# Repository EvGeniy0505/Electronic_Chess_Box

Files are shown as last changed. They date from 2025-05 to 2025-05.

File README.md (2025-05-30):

# 🧠 Electronic Chess Box

**Electronic Chess Box** — это проект умной электронной шахматной доски, разработанный на базе Arduino. 

Он сочетает в себе аппаратную и программную части, позволяя играть в шахматы с использованием физических фигур, при этом отслеживая ходы и взаимодействуя с шахматным движком.

## 📁 Структура проекта

Репозиторий организован следующим образом:

```
Electronic_Chess_Box/
├── .vscode/                 # Настройки среды разработки Visual Studio Code
├── code/                    # Исходный код прошивки и скриптов
│   ├── arduino/             # Код для микроконтроллера Arduino
│   ├── chess_engine/        # Код для нашего шахматного движка
│   └── communication/       # Код для связи Arduino и движка
├── models/                  # 3D-модели и схемы конструкции
├── Умные шахматы.pdf        # Документация проекта
├── Умные шахматы.pptx       # Презентация проекта
├── chess_poster.png         # Постер проекта
└── .gitignore               # Файл исключений Git
```

## ⚙️ Аппаратные компоненты

Arduino Uno — управление сенсорами и считывание ходов.

Герконы — определение положения фигур на доске.

Светодиоды (LED) — индикация возможных ходов и подсказок.

3D-печатные компоненты — корпус и элементы доски.

## 🚀 Начало работы

Сборка аппаратной части: следуйте инструкциям в документации и используйте модели из папки models/ для печати необходимых компонентов.

Прошивка Arduino: загрузите код из папки code/arduino/ с помощью Arduino IDE.

Запуск игры:
```bash
cd code/communication
python3 main.py
``` 
После включения системы, доска готова к игре. Фигуры автоматически распознаются, и возможные ходы подсвечиваются.

## 📄 Документация

**Умные шахматы.pdf** — подробное описание проекта, включая схемы и инструкции.

**Умные шахматы.pptx** — презентация проекта для демонстрации.

**chess_poster.png** — визуальный постер проекта.

## 📬 Обратная связь

Если у вас есть предложения или вы обнаружили ошибки, пожалуйста, создайте **issue** или отправьте **pull request**.

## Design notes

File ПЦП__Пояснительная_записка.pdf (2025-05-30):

## Электронная шахматная доска на герконовых датчиках

Команда

Хальфин Бахтияр | khalfin.br@phystech.edu
Б01-302 | Занимался электроникой и настраивал логику для
| связи всех компонентов. Сделал все модели шахмат-
| ных фигур. Участвовал в написании приложения для
| шахмат.
Евгений Рогов | rogov.ev@phystech.edu
Б01-304 | Проектировал корпус для доски. Занимался печатью
| и лазерной резкой всех компонентов. Участвовал в
| написании приложения для шахмат.
Новикова Полина | novikova.pp@phystech.edu
Б01-304 | Припаяла все элементы к печатной плате, собрала
| матрицу герконов и LED-ленту. Сделала все доку-
| менты для проекта: постер, презентацию и поясни-
| тельную записку.

Причины выбора проекта

С недавнего времени наша команда увлеклась игрой в шахматы. Поэтому мы решили выполнить работу, которая будет сочетать наше хобби и полезный проект, с помощью которого можно будет играть в шахматы не только вдвоём, но и с компьютером. Причём с возможностью физического взаимодействия с фигурами.

Цель проекта

Разработать и изготовить электронную шахматную доску, позволяющую пользователю играть с компьютером. Доска будет оснащена герконовыми датчиками в каждой клетке и магнитами в каждой фигуре для определения ходов, а также LEDподсветкой для индикации возможных ходов и ходов соперника.

Задачи проекта

- Разработать конструкцию шахматной доски с герконами в каждой клетке и магнитами в каждой фигуре;
- Создать программу для определения ходов и взаимодействия с компьютером;
- Разработать систему LED-подсветки для отображения возможных ходов и ходов компьютера/другого игрока;
- Собрать прототип доски и провести тестирование функциональности;
- Настроить программное обеспечение для корректного взаимодействия с доской;
- Провести финальное тестирование и отладку системы.

Описание продукта

Мы разработали умную шахматную доску, способную отслеживать ходы игрока с помощью герконовых датчиков и подсвечивать клетки для следующего действия. Основные функции:

- Распознавание перемещений фигур в реальном времени;
- Подсветка ходов с помощью встроенной светодиодной матрицы;
- Игра с локальным шахматным движком собственного производства;
- Подключение к Lichess.org через API — можно играть с живыми соперниками;
- Поддержка обратной связи: доска сама показывает следующий ход, ожидая действий игрока.

Аппаратная часть построена на Arduino Nano. Программная логика реализована на C++. Возможна интеграция с companion-приложением или удалённым интерфейсом управления.

Решение задач и описание процесса изготовления

1. Корпус для шахматной доски был спроектирован в SolidWorks и изготовлен с помощью лазерной резки;
2. Фигуры были смоделированы в Blender и напечатаны на 3D-принтере;
3. Печатная плата для электроники спроектирована в EasyEDA, затем изготовлена на фрезерном станке;
4. Для герконов была использована макетная плата из-за отсутствия подходящей по размеру печатной платы;
5. Затем был написан код для Arduino и выложен на GitHub (https://github.com/EvGeniy0505/Electronic_Chess_Box) проекта.

Компоненты

Для электроники использовались следующие компоненты:

- Arduino Nano;
- Герконы;
- LED-лента;
- Магниты;
- Bluetooth-модуль;
- BMS-модуль;
- Сдвиговые регистры;
- Модуль понижения напряжения;
- Держатель для аккумуляторов;
- Зарядный модуль.

Существующие аналоги

Конструкция аналогичной шахматной доски описывается, например, в:

1. GoChess (https://particula-tech.com/pages/gochess?_ab=0&_fd=0&_sc=1) — шахматная доска, позволяющая играть по сети с автоматическим перемещением фигур соперника. Поддерживает голосовое управление и подсветку возможных ходов. Недостаток этого аналога — высокая стоимость разработки. В нашем проекте использованы недорогие компоненты при сохранении качественного функционала;
2. DIY Super Smart Chessboard | Play Online or Against Raspberry Pi - Instructables, (https://www.instructables.com/DIY-Super-Smart-Chessboard-Play-Online-or-Against-/)
где создание аналогичной установки описано в 34 шагах. Недостаток — необходимость ручного подтверждения сделанных ходов. В нашем продукте это не требуется.

Можно отметить, что в России отсутствует массовое производство умных шахматных досок.

Тестирование

Приложение для шахмат было протестировано, связь с lichess.org работает. После чего была протестирована доска.
Проведено несколько этапов тестирования:
- Проверка корректной регистрации ходов при различных сценариях перемещения фигур;
- Проверка индикации возможных ходов и подсветки с помощью светодиодной матрицы;
- Тестирование устойчивости Bluetooth-соединения и передачи данных между доской и companion-приложением;
- Интеграционные тесты на связку "доска — шахматный движок — пользователь";
- Тестирование работы доски при игре с живыми соперниками через Lichess API.

Результаты тестов показали высокую надёжность системы: ошибки определения ходов возникали редко и в основном были связаны с недостаточной точностью размещения магнитов. После калибровки доска демонстрировала стабильную и корректную работу.

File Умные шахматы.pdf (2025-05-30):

# Умные шахматы

Новикова Полина
Рогов Евгений
Бахтияр Хальфин

# Цели проекта

- Сделать шахматы с умной подсветкой
- Закрепить навыки полученные в прошлом семестре
- Написать и подключить собственный движок с возможностью игры на lichess.org

# Принцип работы

В каждой фигуре находится магнитик. При поднятии фигуры программа понимает какую из фигур поднял игрок.

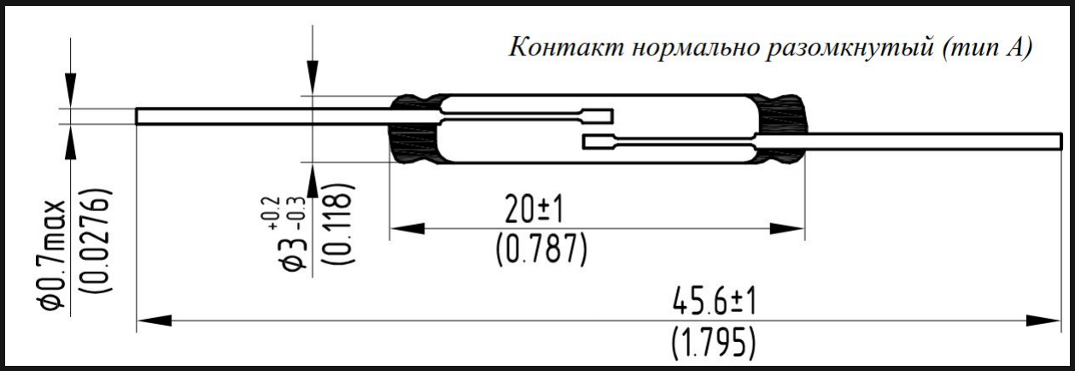
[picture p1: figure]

# Последовательность действий

- Развести и напечатать плату
- Припаять к ней все необходимые детали
- Сделать корпус на лазерном станке, используя технику шип паз
- Распечатать шахматные фигуры на 3d принтере
- Написать собственный движок для игры с компьютером
- Подключить к сайту lichess.org для игры с компьютером на шахматной доске

# Электроника

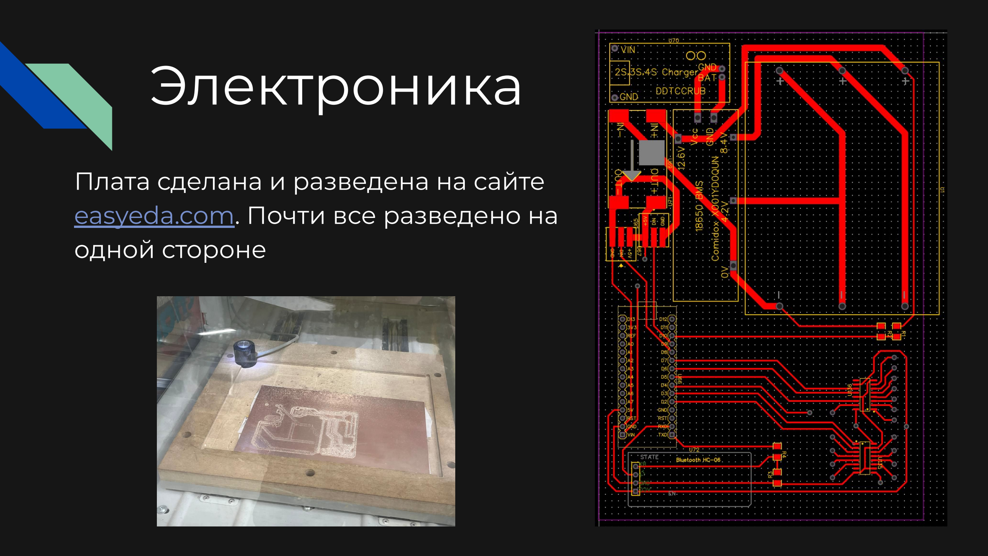
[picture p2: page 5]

Плата сделана и разведена на сайте easyeda.com. Почти все разведено на одной стороне

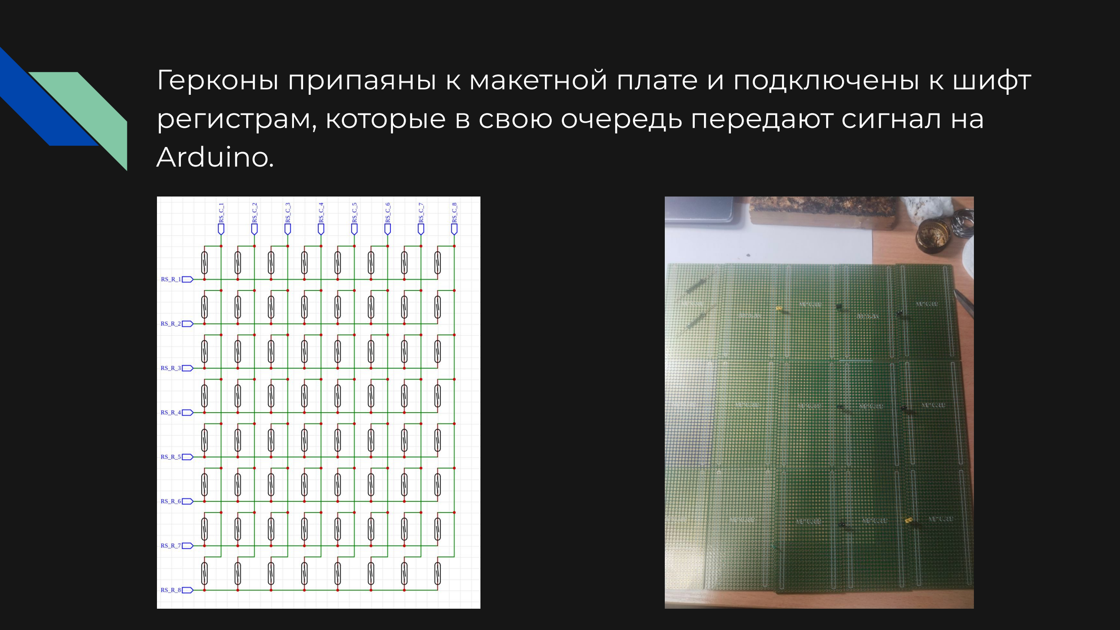
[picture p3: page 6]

Герконы припаяны к макетной плате и подключены к шифт регистрам, которые в свою очередь передают сигнал на Arduino.

# Результат

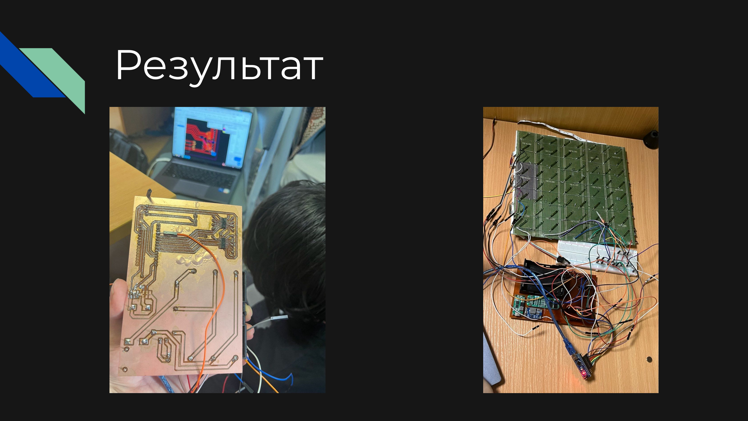
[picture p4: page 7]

# Корпус

Корпус был сделан в программе SolidWorks. После чего мы проверили его сборку и распечатали на лазерном станке

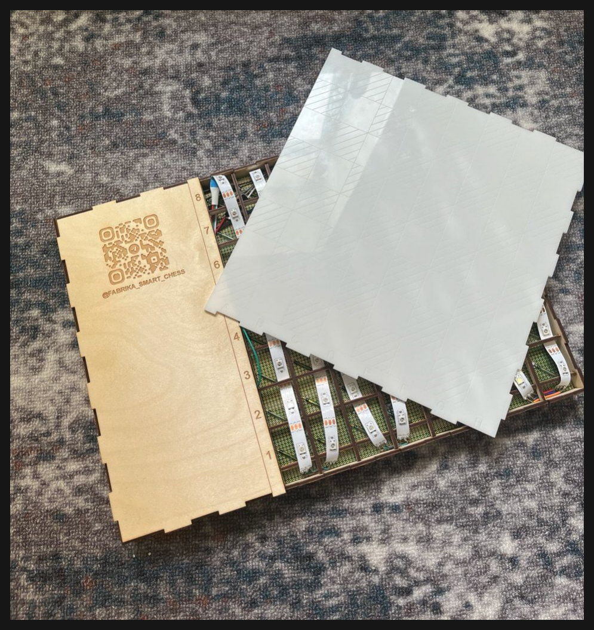
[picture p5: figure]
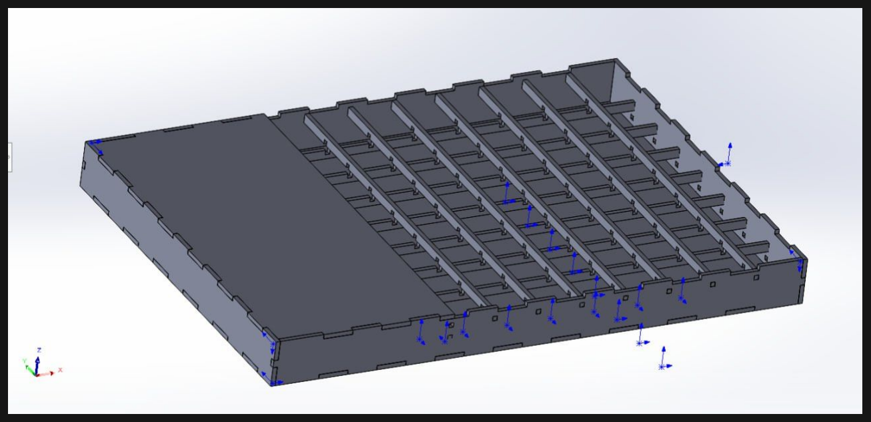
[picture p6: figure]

# Шахматные фигуры

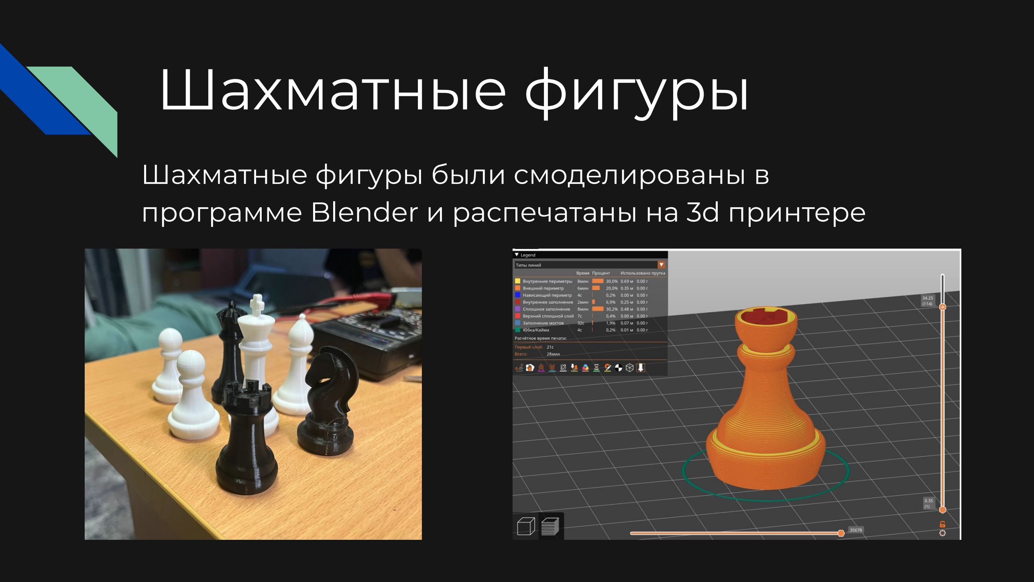
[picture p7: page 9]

Шахматные фигуры были смоделированы в программе Blender и распечатаны на 3d принтере

# Шахматный движок

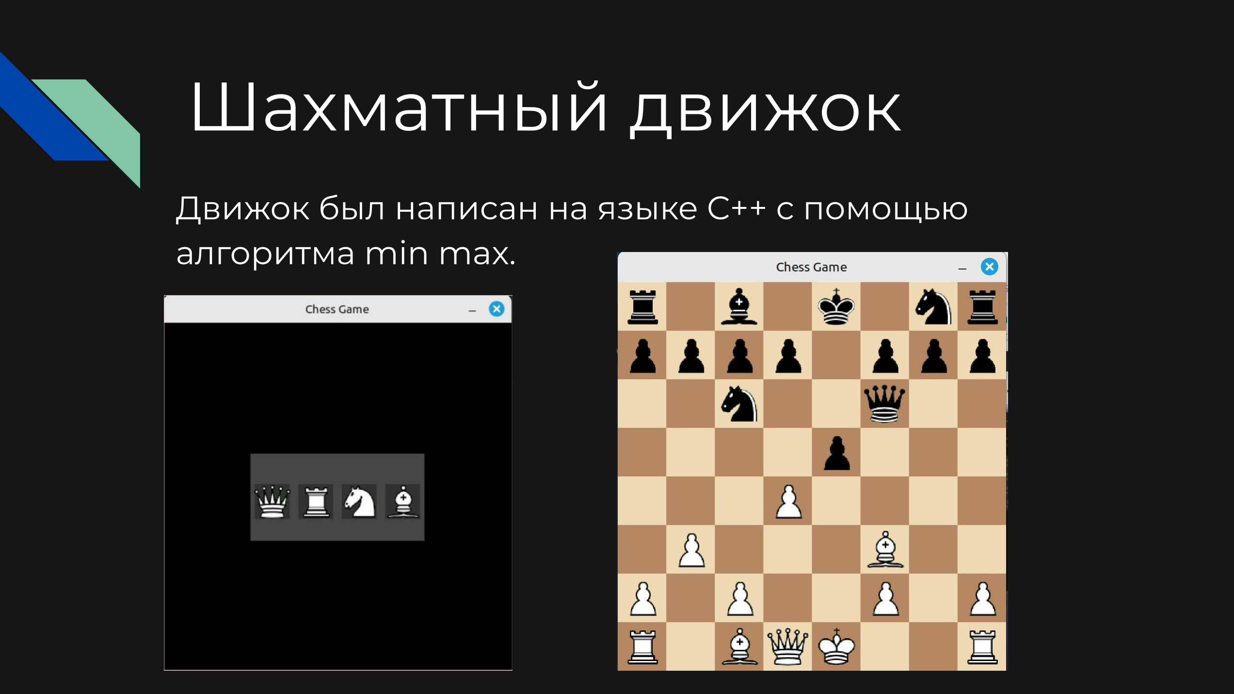
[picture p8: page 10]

Движок был написан на языке C++ с помощью алгоритма min max.

После чего в него добавлена база шахматных дебютов, написана визуализация на основе графической библиотеки sdl2 и подключен к сайту lichess.org

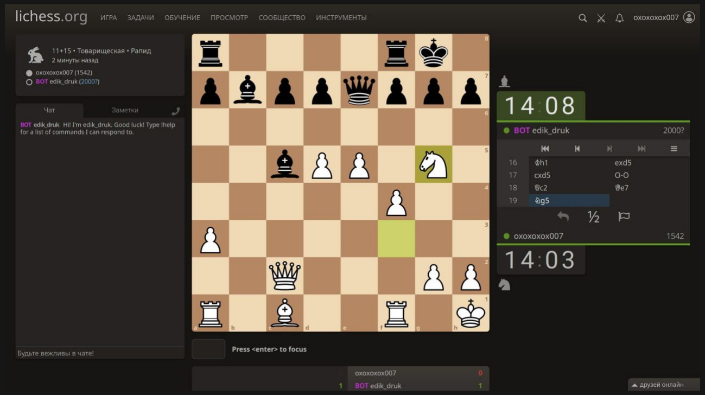
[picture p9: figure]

# Результаты

Доска протестирована нашей командой и работает

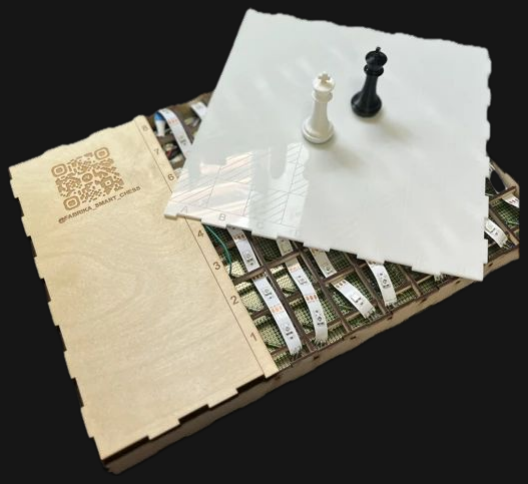
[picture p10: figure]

# Усовершенствование проекта

- Поставить вместо герконовых датчиков NFC метки
- Сделать клетки доски больше или магниты в фигурах
- Сделать каждую ячейку обособленно
- Наладить широкое производство

# Полезные ссылки

Телеграм канал: https://t.me/fabrika_smart_chess Github проекта:
https://github.com/EvGeniy0505/Electronic_Chess_Box Github шахматного движка:
https://github.com/EvGeniy0505/Chess_Engine

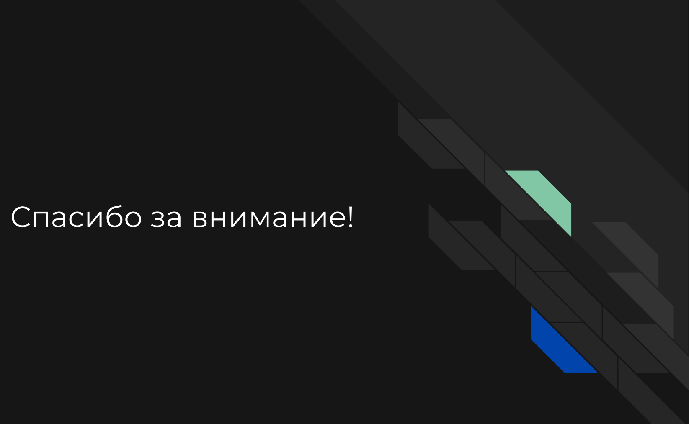
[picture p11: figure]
Спасибо за внимание!

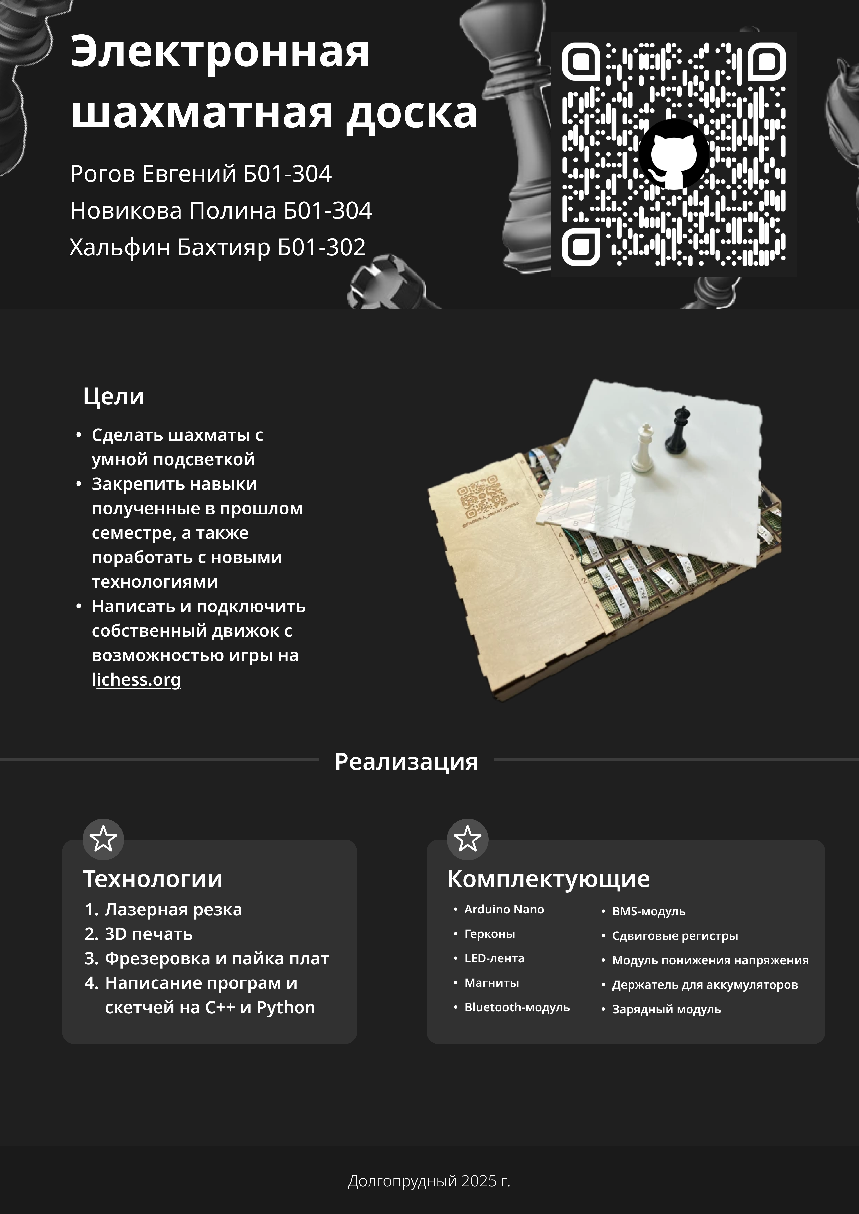
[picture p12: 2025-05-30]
chess_poster.png

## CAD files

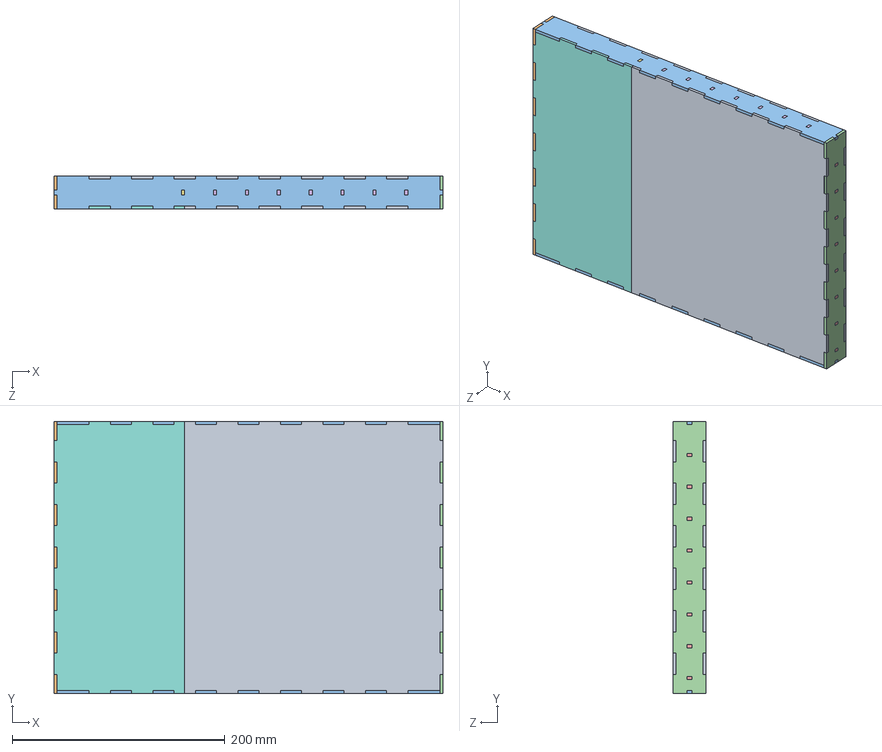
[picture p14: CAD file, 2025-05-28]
models/board/assembly.SLDASM
366.0 x 256.0 x 31.0 mm
bottom
left
front x 2
right
перегородка x 8
перегородка2 x 7
перегородка3
top1
top2

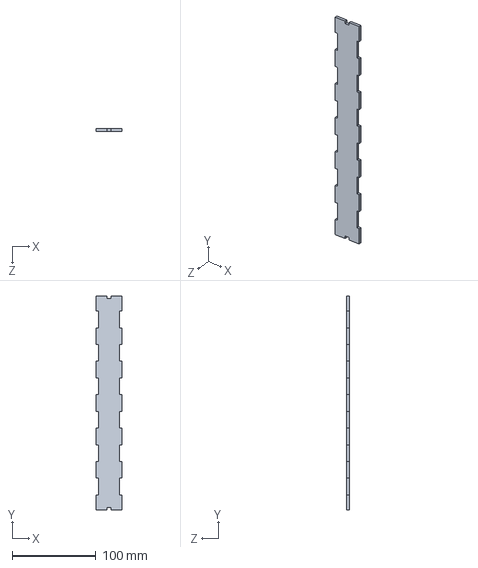
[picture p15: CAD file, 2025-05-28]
models/board/left.SLDPRT
31.0 x 256.0 x 3.00 mm

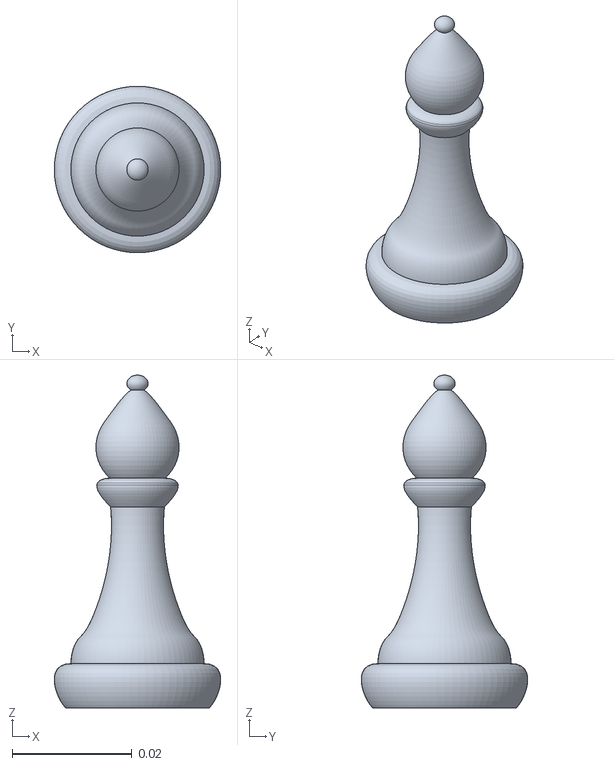
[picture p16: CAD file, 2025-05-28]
models/pieces/bishop.stl
0.0278 x 0.0278 x 0.0557

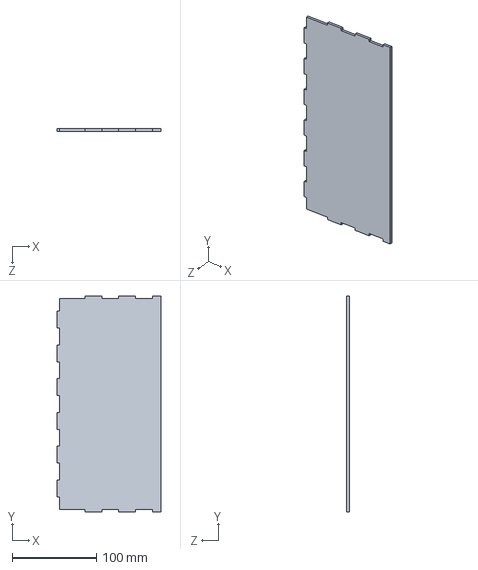
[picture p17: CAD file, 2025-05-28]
models/board/top_left.SLDPRT
123.0 x 256.0 x 3.00 mm

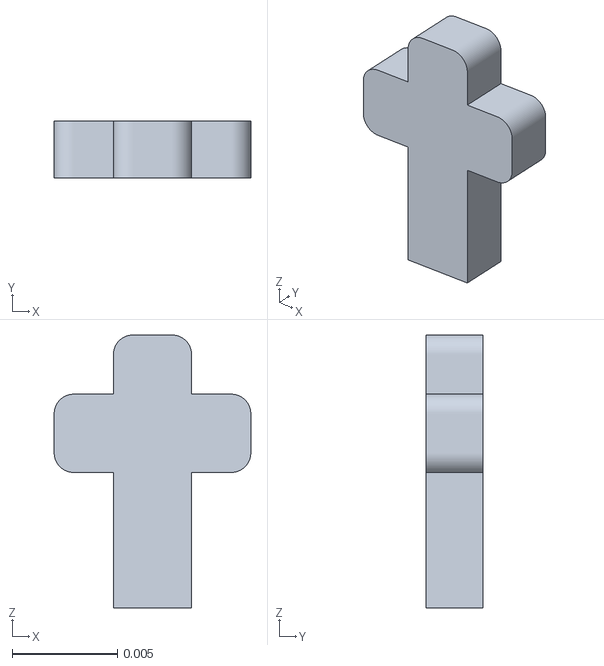
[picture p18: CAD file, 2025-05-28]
models/pieces/king-cross.stl
0.00932 x 0.00269 x 0.0129

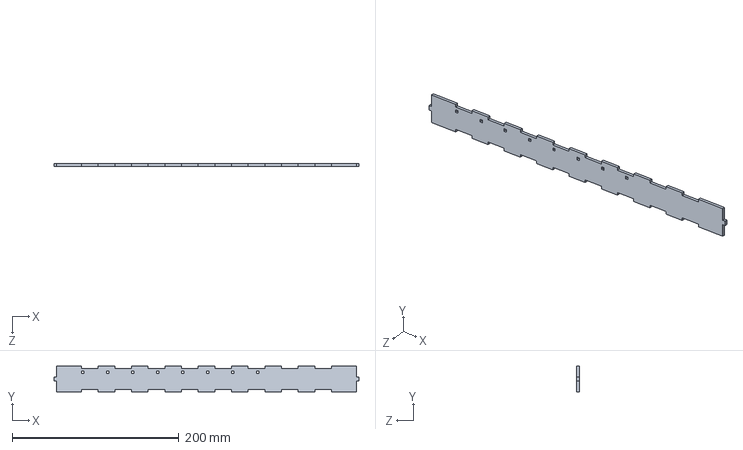
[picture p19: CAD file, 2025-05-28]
models/board/front.SLDPRT
366.0 x 31.0 x 3.00 mm

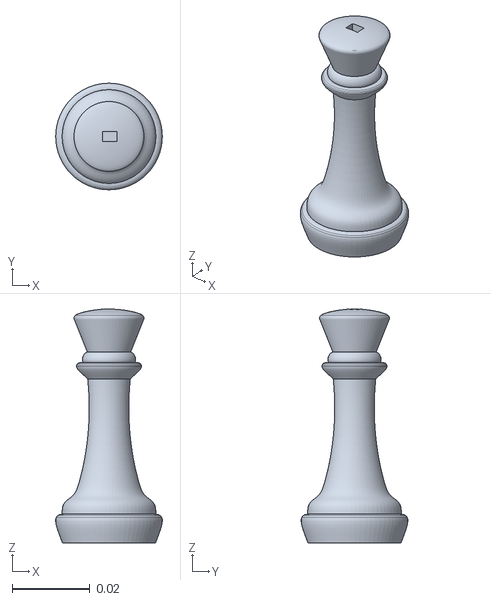
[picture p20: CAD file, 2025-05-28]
models/pieces/king-body.stl
0.0274 x 0.0274 x 0.0602

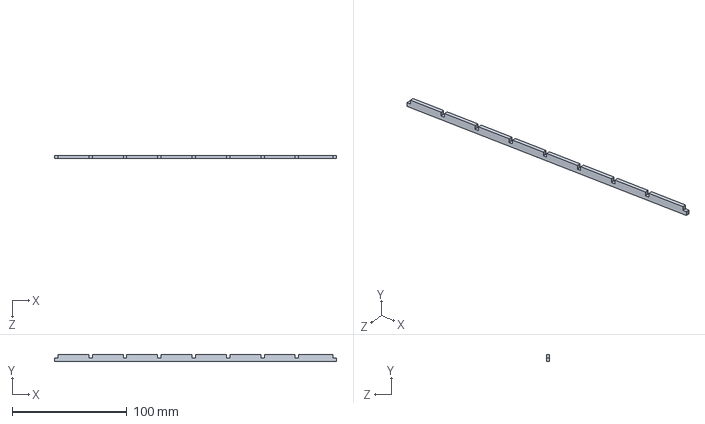
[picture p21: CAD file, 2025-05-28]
models/board/separator.SLDPRT
246.0 x 6.00 x 3.00 mm

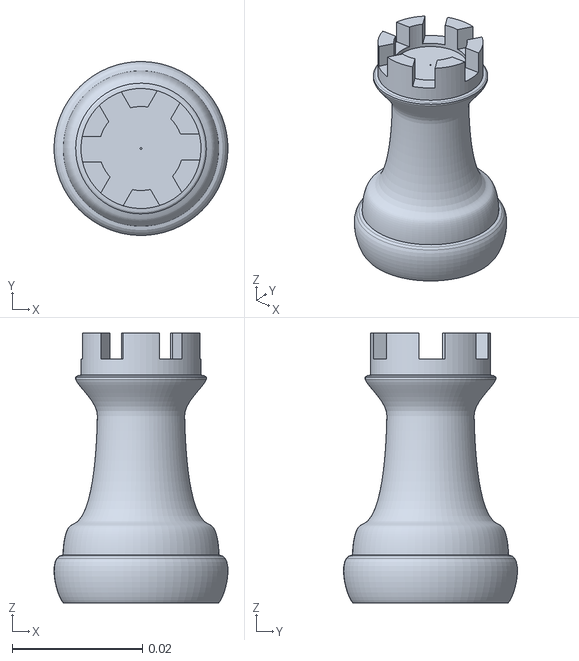
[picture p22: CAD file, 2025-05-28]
models/pieces/rook.stl
0.0268 x 0.0268 x 0.0415

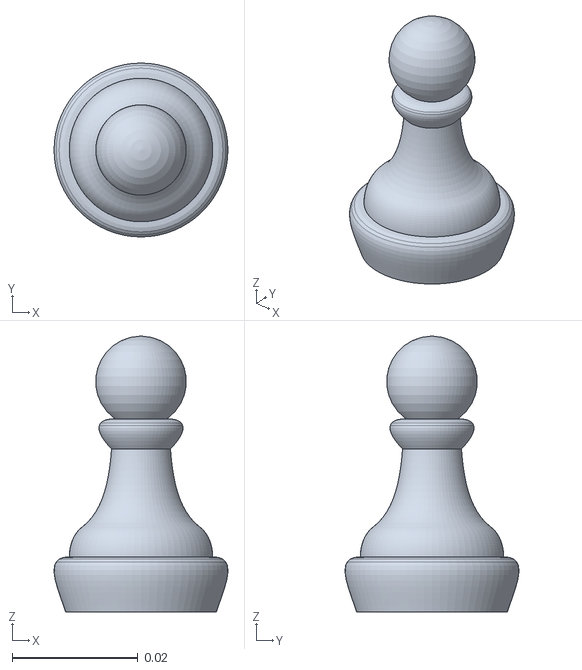
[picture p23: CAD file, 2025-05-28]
models/pieces/pawn.stl
0.0277 x 0.0277 x 0.0439

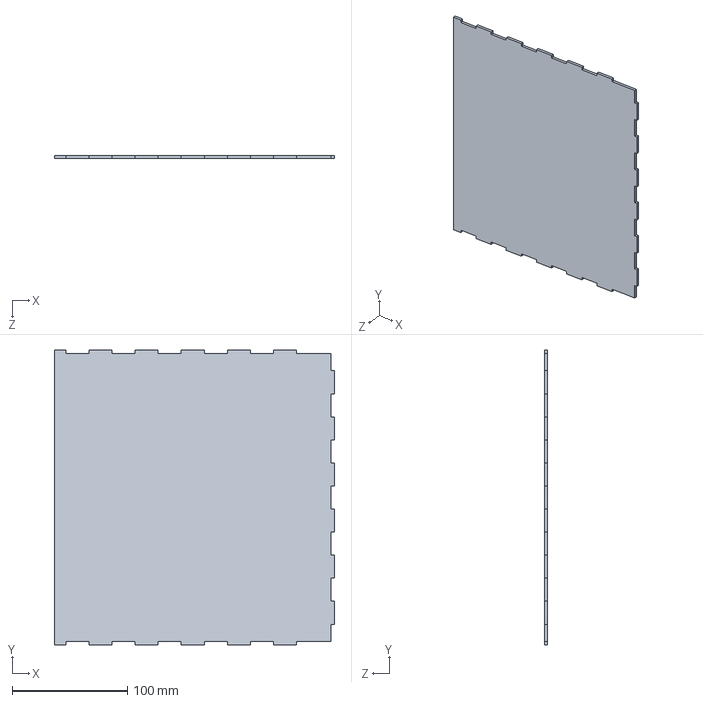
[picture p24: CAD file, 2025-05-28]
models/board/top_right.SLDPRT
243.0 x 256.0 x 3.00 mm

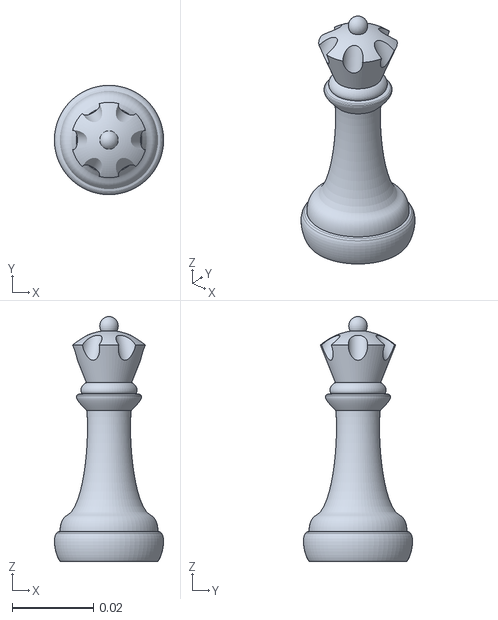
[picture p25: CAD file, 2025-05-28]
models/pieces/queen.stl
0.0269 x 0.0269 x 0.0603

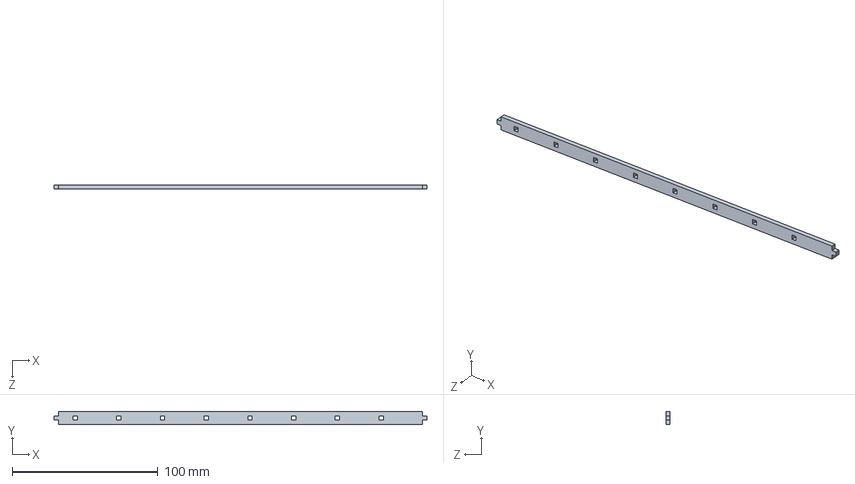
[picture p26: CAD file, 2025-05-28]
models/board/separator3.SLDPRT
256.0 x 9.00 x 3.00 mm

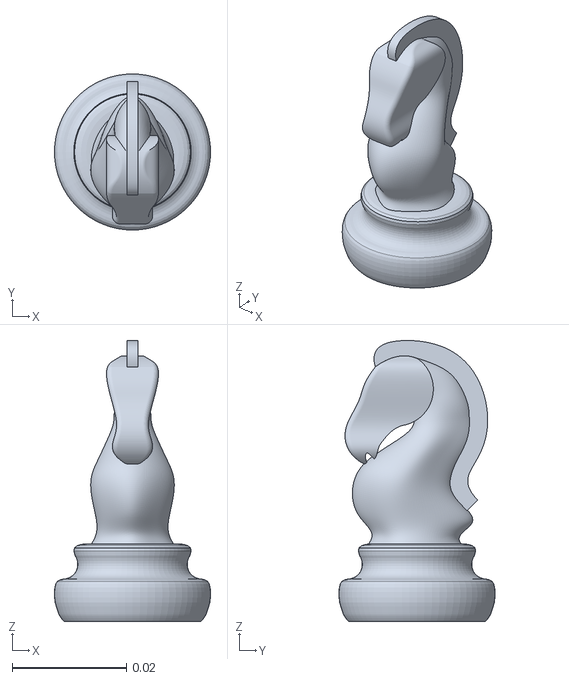
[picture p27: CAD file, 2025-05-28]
models/pieces/knight.stl
0.0274 x 0.0274 x 0.0493

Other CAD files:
models/board/right.SLDPRT
models/board/bottom.SLDPRT
models/board/separator2.SLDPRT

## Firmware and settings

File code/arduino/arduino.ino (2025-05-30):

#include "config.h"
#include "shift_registers.h"
#include "reed_matrix.h"
#include "bluetooth.h"
#include "led_control.h"  // Добавляем заголовочный файл для управления светодиодами

ShiftRegisters shiftRegisters;
ReedMatrix reedMatrix(shiftRegisters);
Bluetooth bluetooth;
LedControl ledControl(reedMatrix);  // Создаем экземпляр управления светодиодами

// Для отслеживания изменений
byte lastBoardState[BOARD_SIZE] = {0};

void setup() {
    Serial.begin(115200);
    
    shiftRegisters.init();
    reedMatrix.init();
    bluetooth.init();
    ledControl.init();  // Инициализируем светодиоды
    
    Serial.println("Chess Board Initialized");
    Serial.println("Waiting for Bluetooth connection...");
    
    // Первоначальное обновление светодиодов
    ledControl.updateFromReedMatrix();
}

void loop() {
    // 1. Сканируем состояние герконов
    reedMatrix.scan();
    
    // 2. Проверяем изменения
    //if (hasBoardChanged()) {
        // 3. Отправляем только при изменениях
        bluetooth.sendBoardState(reedMatrix.getBoardState());
       
        printMatrixState(reedMatrix.getBoardState());
        
        // Обновляем светодиоды при изменении состояния
        ledControl.updateFromReedMatrix();
    //}
    
    // 4. Проверяем обратную связь
    checkBluetoothFeedback();
    
    delay(50); // Уменьшенная задержка
}

// Остальные функции остаются без изменений

bool hasBoardChanged() {
    byte* current = reedMatrix.getBoardState();
    for (byte i = 0; i < BOARD_SIZE; i++) {
        if (current[i] != lastBoardState[i]) {
            memcpy(lastBoardState, current, BOARD_SIZE);
            return true;
        }
    }
    return false;
}

void printMatrixState(byte* boardState) {
    Serial.println("Matrix state (Debug):");
    for (byte row = 0; row < BOARD_SIZE; row++) {
        for (byte col = 0; col < BOARD_SIZE; col++) {
            Serial.print((boardState[col] & (1 << row)) ? "1 " : "0 ");
        }
        Serial.println();
    }
    Serial.println();
}

void checkBluetoothFeedback() {
    while (bluetooth.btSerial.available()) {
        String feedback = bluetooth.btSerial.readStringUntil('\n');
        feedback.trim();
        
        Serial.print("[BT Feedback] ");  // Метка для отладки
        Serial.println(feedback);  // Вывод всего сообщения
        
        if (feedback.startsWith("ERROR:")) {
            String errorMsg = feedback.substring(6);
            Serial.print("Ошибка хода: ");
            Serial.println(errorMsg);
        }
        else if (feedback.startsWith("MOVE:")) {
            String move = feedback.substring(5);
            Serial.print("Принят ход: ");
            Serial.println(move);
        }
    }
}

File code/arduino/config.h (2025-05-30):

#ifndef CONFIG_H
#define CONFIG_H

// Пины 74HC595 (выходные - столбцы)
#define LATCH_PIN_OUT 6     // CS_595 (Latch)
#define DATA_PIN_OUT 5       // DAT_595
#define CLOCK_PIN_OUT 7      // CLK_595

// Пины 74HC165 (входные - строки)
#define LATCH_PIN_IN 3       // LAT_165 (Load)
#define DATA_PIN_IN 4        // DAT_165
#define CLOCK_PIN_IN 2       // CLK_165

// Bluetooth пины
#define BT_TX_PIN 8          // Пин TX Bluetooth
#define BT_RX_PIN 9         // Пин RX Bluetooth

// Константы
#define BOARD_SIZE 8         // Размер шахматной доски (8x8)

// LED Configuration
#define LED_PIN 11           // Пин, к которому подключена лента
#define LED_COUNT 64        // 8x8 = 64 светодиода
#define LED_ON_COLOR strip.Color(0, 255, 0)  // Зеленый цвет для занятых клеток
#define LED_OFF_COLOR strip.Color(0, 0, 0)   // Выключенный светодиод

#endif

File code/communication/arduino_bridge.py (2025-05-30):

import os
import subprocess
import time
import serial
from collections import defaultdict, deque

BOARD_SIZE = 8
SAMPLE_SIZE = 5
STABLE_THRESHOLD = 3
FIFO_IN_PATH = "./build/arduino_in"
FIFO_OUT_PATH = "./build/arduino_out"

class ChessBoardAnalyzer:
    def __init__(self, serial_conn, fifo_path="/tmp/arduino_out"):
        self.prev_stable_state = None
        self.intermediate_state = None
        self.ser = serial_conn
        self.processing = False
        self.move_timeout = 0
        self.sample_buffer = deque(maxlen=SAMPLE_SIZE)
        self.stable_counter = 0
        self.empty_board = '0' * (BOARD_SIZE * BOARD_SIZE)  # Состояние пустой доски
        
        try:
            self.fifo = open(fifo_path, "w")
            print(f"Connected to FIFO at {fifo_path}")
        except Exception as e:
            print(f"Failed to open FIFO: {e}")
            self.fifo = None

    def get_most_common_state(self):
        if not self.sample_buffer:
            return None
            
        state_counts = defaultdict(int)
        for state in self.sample_buffer:
            state_counts[state] += 1
            
        return max(state_counts.items(), key=lambda x: x[1])[0]

    def is_state_stable(self, new_state):
        if len(self.sample_buffer) < self.sample_buffer.maxlen:
            return False
            
        most_common = self.get_most_common_state()
        if most_common == new_state:
            self.stable_counter += 1
        else:
            self.stable_counter = 0
            
        return self.stable_counter >= STABLE_THRESHOLD

    def is_empty_board(self, state):
        """Проверяет, является ли доска пустой"""
        return state == self.empty_board

    def send_to_cpp(self, move):
        if self.fifo:
            try:
                self.fifo.write(f"{move}\n")
                self.fifo.flush()
                print(f"Sent to C++: {move}")
            except Exception as e:
                print(f"Error writing to FIFO: {e}")

    def send_error(self, message):
        clean_message = ''.join(c for c in message if ord(c) < 128)
        try:
            self.ser.write(f"ERROR:{clean_message}\n".encode('ascii'))
            print(f"Sent error: {clean_message}")
        except Exception as e:
            print(f"Failed to send error to serial: {e}")

    @staticmethod
    def square_to_notation(row, col):
        return chr(ord('a') + col) + str(BOARD_SIZE - row)

    def is_valid_move(self, from_sq, to_sq):
        try:
            if not (isinstance(from_sq, (tuple, list))) or not (isinstance(to_sq, (tuple, list))):
                raise ValueError("Coordinates must be tuple/list")
                
            from_row, from_col = map(int, from_sq)
            to_row, to_col = map(int, to_sq)
            
            board_range = range(BOARD_SIZE)
            if (from_row not in board_range or from_col not in board_range or
                to_row not in board_range or to_col not in board_range):
                self.send_error("Coordinates out of board")
                return False
                
            if (from_row, from_col) == (to_row, to_col):
                self.send_error("Piece didn't move")
                return False
                
            return True
        
        except (ValueError, TypeError) as e:
            self.send_error(f"Move validation error: {str(e)}")
            return False

    def analyze_move(self, old_state, new_state):
        """Analyze board changes and validate moves"""
        # Если доска пустая, не анализируем ходы
        if self.is_empty_board(new_state):
            self.intermediate_state = None
            return None
            
        changes = []
        
        for row in range(BOARD_SIZE):
            for col in range(BOARD_SIZE):
                idx = row*BOARD_SIZE + col
                if old_state[idx] != new_state[idx]:
                    changes.append((row, col, old_state[idx], new_state[idx]))
        
        # Если нет изменений, выходим
        if not changes:
            return None
        
        # Поднятие фигуры
        if len(changes) == 1:
            (r, c, old, new) = changes[0]
            
            if old == '1' and new == '0':
                self.intermediate_state = new_state
                self.move_timeout = time.time() + 2.0
                print("Piece lifted, waiting for placement...")
                return None
                
            elif old == '0' and new == '1' and self.intermediate_state is not None:
                from_sq = None
                for row in range(BOARD_SIZE):
                    for col in range(BOARD_SIZE):
                        if (self.intermediate_state[row*BOARD_SIZE + col] == '0' and 
                            old_state[row*BOARD_SIZE + col] == '1'):
                            from_sq = (row, col)
                            break
                    if from_sq is not None:
                        break
                
                if from_sq is not None:
                    to_sq = (r, c)
                    if self.is_valid_move(from_sq, to_sq):
                        move = self.square_to_notation(*from_sq) + self.square_to_notation(*to_sq)
                        self.intermediate_state = None
                        return move
                return None
        
        # Полный ход
        elif len(changes) == 2:
            (r1, c1, old1, new1), (r2, c2, old2, new2) = changes
            
            if old1 == '1' and new1 == '0' and old2 == '0' and new2 == '1':
                from_sq = (r1, c1)
                to_sq = (r2, c2)
                if self.is_valid_move(from_sq, to_sq):
                    self.intermediate_state = None
                    return self.square_to_notation(r1, c1) + self.square_to_notation(r2, c2)
                return None
                    
            elif old1 == '0' and new1 == '1' and old2 == '1' and new2 == '0':
                from_sq = (r2, c2)
                to_sq = (r1, c1)
                if self.is_valid_move(from_sq, to_sq):
                    self.intermediate_state = None
                    return self.square_to_notation(r2, c2) + self.square_to_notation(r1, c1)
                return None
        
        # Рокировка
        elif len(changes) == 4:
            moved = [(r,c) for r,c,old,new in changes if old == '1' and new == '0']
            arrived = [(r,c) for r,c,old,new in changes if old == '0' and new == '1']
            
            if len(moved) == 2 and len(arrived) == 2:
                if {moved[0][1], moved[1][1], arrived[0][1], arrived[1][1]} == {0, 2, 3, 4}:
                    self.intermediate_state = None
                    return "O-O-O"
                elif {moved[0][1], moved[1][1], arrived[0][1], arrived[1][1]} == {4, 5, 6, 7}:
                    self.intermediate_state = None
                    return "O-O"
        
        # Взятие
        elif len(changes) == 3:
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

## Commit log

2025-05-28 feature: add models
    [assembly.SLDASM, bishop.stl, bottom.SLDPRT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]
2025-05-29 feature: add connection with board
